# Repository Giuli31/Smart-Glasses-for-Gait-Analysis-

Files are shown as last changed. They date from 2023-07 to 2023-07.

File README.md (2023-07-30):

# Smart Glasses for Gait Analysis in Parkinson’s Disease 
## Table of contents
* [General info](#general-info)
* [Technologies](#technologies)
* [How To Use](#how-to-use)

## General info
Parkinson’s disease (PD) is one of the most common neurodegenerative disorders of the central nervous system, which predominantly affects patients’ motor functions, movement, and stability. In recent years, there has been an increase in the usage of wearable sensors for PD symptom monitoring aiming at anticipating the disease diagnosis and thus providing a most efficient quality of care. In this context, the developed device aims to provide objective information on the motor state, analysing the patient's gait and classifying it. In order to accomplish this task, the SGGA device is based on the Timed Up and Go (TUG) test. This is a simple test to measure a person’s level of mobility. It measures the time it takes for a person to get up from a chair, walk three meters, turn around, return to the chair and sit down again. Some sources suggest that a score of 10 seconds or less indicates normal mobility; times between 11 and 20 seconds are within normal limits for elderly with fragility and disabled patients; times longer than 20 seconds indicate that the person needs external assistance and the need for further examinations and interventions. A score greater than 30 seconds suggests that the person may be prone to falls. The TUG was developed from a more articulated test, the Get-up and Go. The SGGA device isn't a classifier of Parkinson’s disease, but it can be a useful tool for the study of symptoms and progression of this disease. 

## Technologies
Project is created with:
* EAGLE - for the design of the PCB
* PSoC Creator - for the program of the microcontroller 
* PyQt5 - for the development the graphical user interface

## How To Use
* [Physical Device](#physical-device)
* [Interface](#interface)
* [Acquisition](#acquisition)
* [Bugs](#bugs)

### Physical Device
The SGGA device is a wearable device composed by two main parts. The first is a small case equipped with accelerometer and wearable on the own glasses or given glasses. The second part is a bigger case that contains the PCB and its components. It's equipped with a belt that must be fastened around the patient’s waist. On the short side of the case, it's possible to check the state of the SGGA device thanks to the presence of two LEDs. The red LED shows that the device is powered, so it works. The green LED shows the connection established between the device and the application. In particular, the green flashing LED indicates that the device is ready to send data to the application, while, when the green LED becomes fixed, it indicates that the device is sending data registered by the accelerometer to the application. 

### Interface
The graphic user interface allows the user to visualize the results of the Timed Up and Go (TUG) test. On the right side of the screen, it is possible to see a graph that shows the acceleration trend over time. On the left side there are two tabs: "Acquisition" and "Excel files". 
The tab "Acquisition" contains buttons "Start Acquisition", "Stop Acquisition", "Save Data", "New Session" and "Search for device". Here it is also possible to visualize a timer and a steps counter. 
The tab "Excel files" shows past acquisitions that are saved on Excel files named with data and progression number of session. Clicking on one of these files, it is possible to visualize on the screen a number between 0 and 2 that indicates the class of the result (0 - Normal Gait, 1 - Require further examinations, 2 - Patient need assistance). This classification is made using a machine learning model, the Decision Trees, that is trained using a set of acquisitions based on TUG test permed by healthy subject trying also to reproduce the gait of impaired people. 

### Acquisition 
The first step of the acquisition is the preparation of the patient. He/She should wear the belt and place the case on the side so that the LED lights are visible. Red LED will light up when the device is connected to the power supply. After that, the patient must wear glasses equipped with the second smaller case. Let sit the patient in the chair and so he/she is ready for the test. 

Now, the user has to run the application using the Python file named "FinalGUI.py" and start the pairing of the device with the application. Once the GUI is open, the user must push the button "Search for device" in order to connect the device, if the connection is successful the green LED will start flashing. At this point, the device is ready for start the acquisition. 

When the patient is ready to perform the test, the user has to push the button "Start Acquisition" and the timer and the steps counter start at the same time. On the graph it's possible to visualize in real-time the acceleration trend of the patient's walk. 

Once the patient has completed the test, the user has to push the button "Stop acquisition". At this point a dynamic window will open and it will show the result of the test, classifying it into "Normal gait detected", "Anomalous gait detected. Further examinations suggested" or "Serious anomalies on gait detected. Subject may require assistances". On the same window, it is asked to the user if he wants to save the result of test, in positive case clicking on "Yes". 

Now it is possible to start a new acquisition pushing again the button "Start Acquisition". 

At the end of the test, it is possible to save the entire session of acquisitions pushing the button "Save Data". These data are saved in files contained in the tab "Excel files". 

In order to start a new session of acquisitions, the user has to push the button "New session" and repeat all the previous steps. 

### Bugs
During the pairing between device and application may happen that the device fails to access the serial port. In this case, a dynamic window will open showing the wrong serial port and the message "ERROR PORT CONNECTION: ". It is recommended to reset the application.

(This project is the result of teamwork)

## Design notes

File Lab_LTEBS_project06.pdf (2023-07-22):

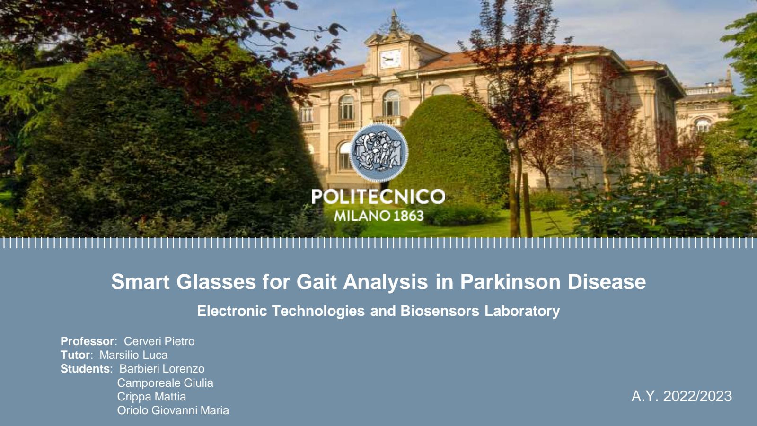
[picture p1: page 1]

# Titolo presentazione sottotitolo

## Milano, XX mese 20XX

## Smart Glasses for Gait Analysis in Parkinson Disease

Electronic Technologies and Biosensors Laboratory

A.Y. 2022/2023

Professor: Cerveri Pietro
Tutor: Marsilio Luca
Students: Barbieri Lorenzo Camporeale Giulia
Crippa Mattia
Oriolo Giovanni Maria

## Introduzione e contesto

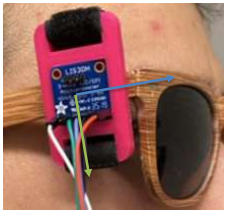
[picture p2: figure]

Electronic Technologies and Biosensors Laboratory

Obiettivo del device?

Come?

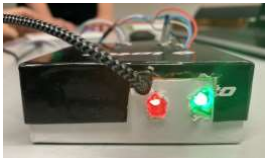
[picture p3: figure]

Contesto di utilizzo? Ausilio valutazione condizione del paziente, test di prima valutazione/conoscitivo. Può essere utilizzato sia in ambito clinico che domiciliare con ausilio persona esterna (anche non qualificata).

Classificare camminata del paziente

TUG test
Acquisizione parametri inerziali e temporali

Obiettivo:
Analisi preliminare della capacità di fornire informazioni oggettive sullo stato motorio di pazienti Parkinson da parte di occhiali smart

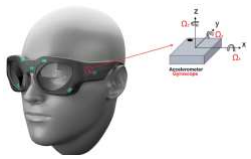
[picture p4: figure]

Protocollo sperimentale:
TUG test indossando occhiali e compilazione due questionari (target)

Conclusioni:
Occhiali smart si sono dimostrati potenzialmente utili a fornire informazioni quantitative riguardo lo stato dei pazienti Parkinson

## Stato dell'arte: revisione della letteratura

https://doi.org/10.1101/2022.10.22.22281214

## Hardware setup

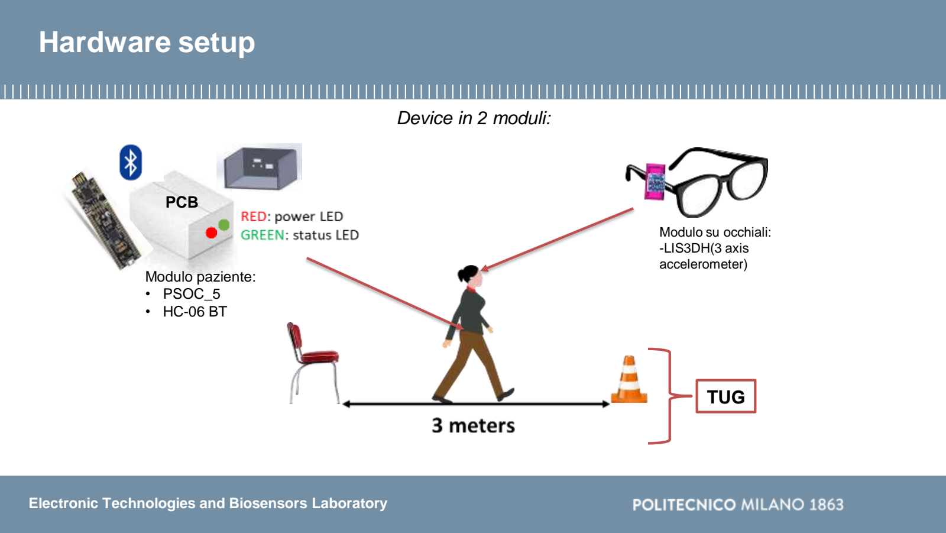
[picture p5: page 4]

PCB

Modulo paziente:
- PSOC_5
- HC-06 BT

TUG

Device in 2 moduli:

Modulo su occhiali:
-LIS3DH(3 axis
accelerometer)

## Software integration

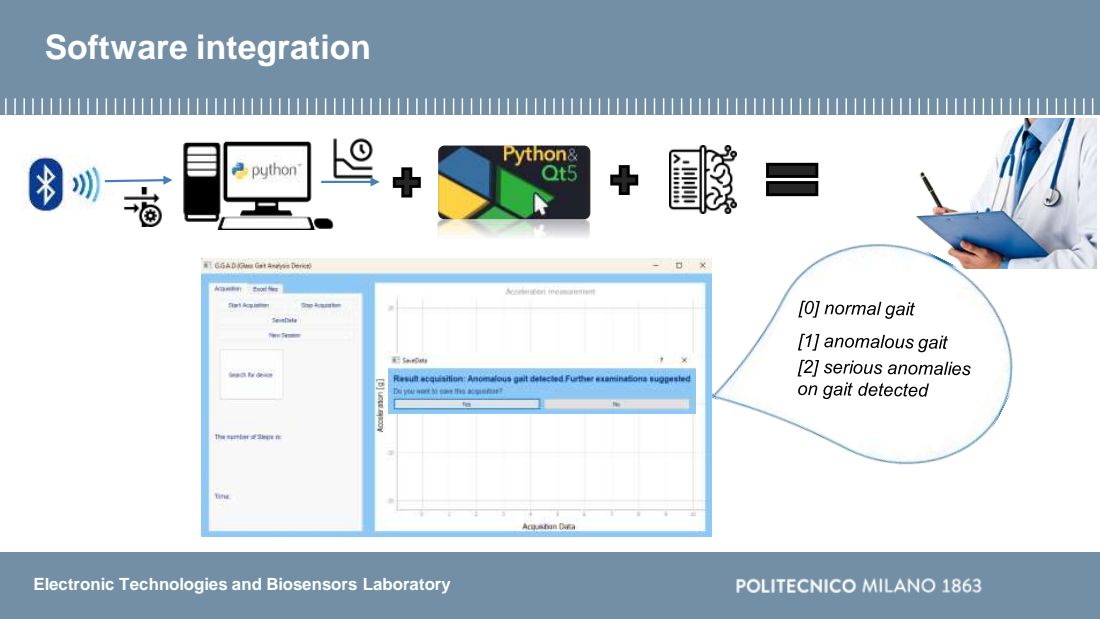
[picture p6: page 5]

4 soggetti sani, età 24 anni (20 –30 sessioni)

Cammino anomalo simulato (FOG, ridotta

mobilità)

## Experimental setup

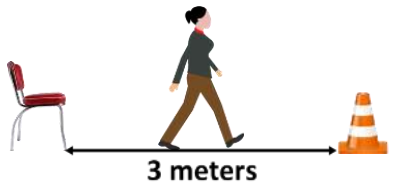
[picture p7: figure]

Posizionamento sensore

Soggetti coinvolti

Classificazione a 3 stati

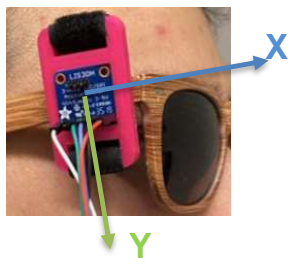
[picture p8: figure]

Ai soggetti è stato richiesto il tipo di

cammino simulato alla fine di ogni sessione.

Target inserito manualmente.

[0] = normal [1] = anomalous [2] = assistance

Protocollo sperimentale

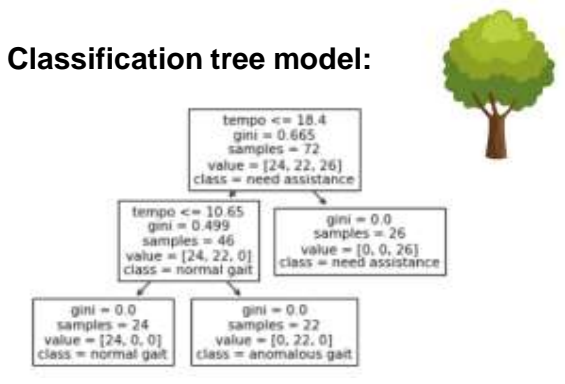
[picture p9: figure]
Classification tree model:
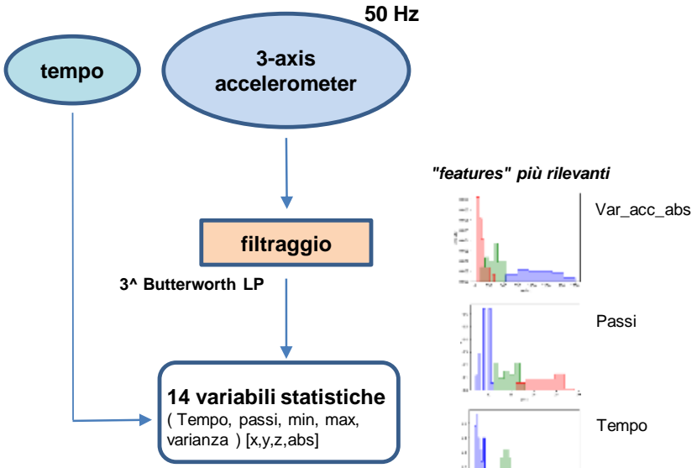
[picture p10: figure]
3-axis accelerometer; filtraggio; tempo; 14 variabili statistiche; ( Tempo, passi, min, max, varianza ) [x,y,z,abs]; Var_acc_abs; Tempo; Passi; 3^ Butterworth LP; "features" più rilevanti

Tempo (t) come discriminante assoluta:

normal gait | t < 10.65 s
anomalous gait | 10.65 s < t < 18.4 s
need assistance | t > 18.4 s

## Data processing e model training

- Connessione tra microcontrollore e PC stabile e veloce tramite bluetooth
- Definito un valido algoritmo per il conteggio dei passi
- Implementazione di una semplice interfaccia grafica con l'utente (GUI)
- Classificazione three-state del paziente tramite modello ML
- Progetto e realizzazione PCB
- Modello CAD 3D per il case

## Conclusioni

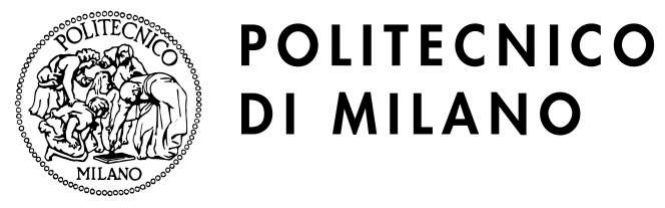
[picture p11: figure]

# Thank you for your attention!

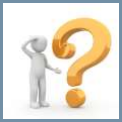
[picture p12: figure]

# Any question?

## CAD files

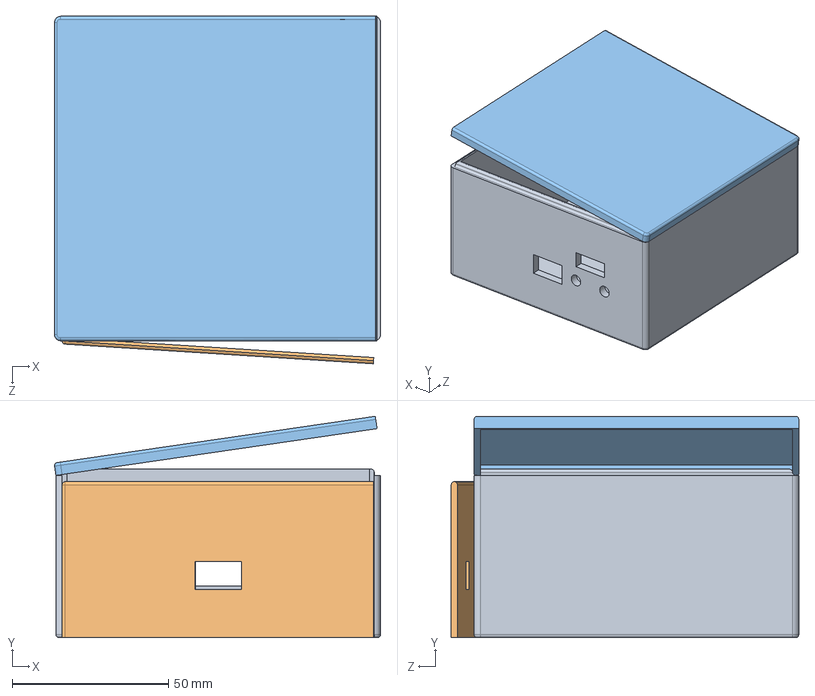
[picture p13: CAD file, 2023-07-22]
Case_3D/Assieme_final.SLDASM
104.4 x 70.9 x 111.4 mm
ParteA_final
ParteC_final
ParteB_final

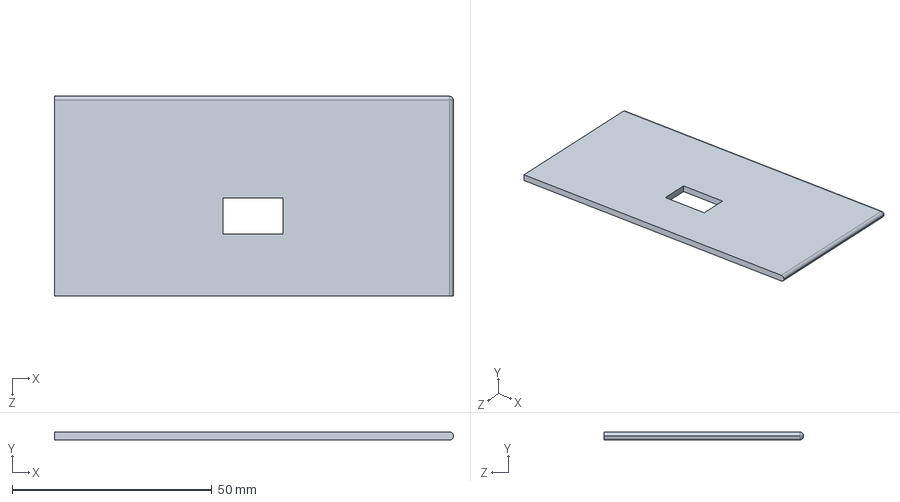
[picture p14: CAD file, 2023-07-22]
Case_3D/ParteC_final.SLDPRT
100.0 x 2.00 x 50.0 mm

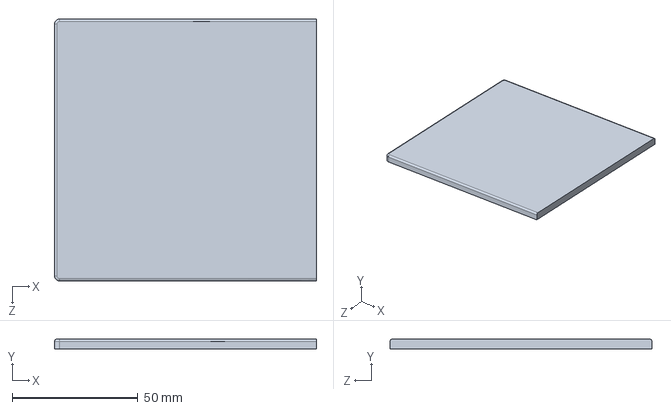
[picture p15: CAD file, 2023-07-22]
Case_3D/ParteB_final.SLDPRT
104.0 x 4.00 x 104.0 mm

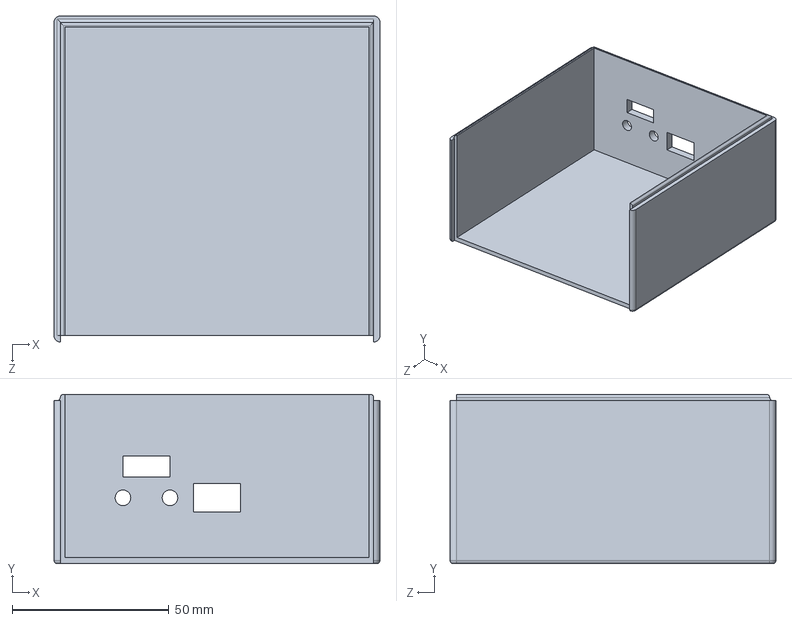
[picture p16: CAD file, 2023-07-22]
Case_3D/ParteA_final.SLDPRT
104.0 x 54.0 x 104.0 mm

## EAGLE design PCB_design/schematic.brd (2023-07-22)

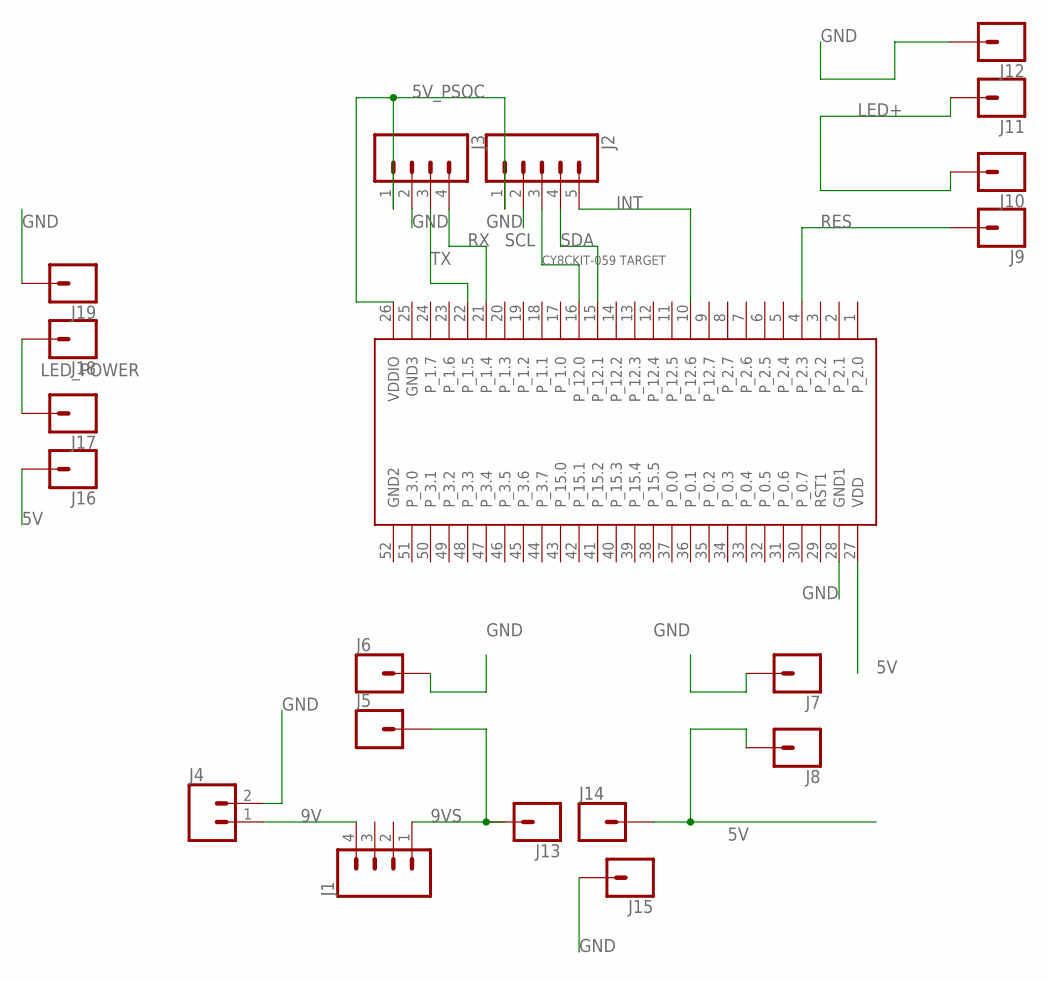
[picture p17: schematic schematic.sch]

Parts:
J1, J3: CONN_041X04_NO_SILK; 1X04_NO_SILK
J2: CONN_05NO_SILK; 1X05_NO_SILK
J4: CONN_021X02_NO_SILK; 1X02_NO_SILK
J5, J6, J7, J8, J9, J10, J11, J12, J13, J14, J15, J16, J17, J18, J19: CONN_01PTH_NO_SILK_YES_STOP; 1X01_NO_SILK
U$2: CY8CKIT-059_TARGET_3

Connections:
5V: J8.1, J14.1, J16.1, U$2.27 (VDD)
5V_PSOC: J2.1, J3.1, U$2.26 (VDDIO)
9V: J1.4, J4.1
9VS: J1.1, J5.1, J13.1
GND: J2.2, J3.2, J4.2, J6.1, J7.1, J12.1, J15.1, J19.1, U$2.28 (GND1)
GND2: U$2.52 (GND2)
GND3: U$2.25 (GND3)
INT: J2.5, U$2.10 (P_12.6)
LED+: J10.1, J11.1
LED_POWER: J17.1, J18.1
RES: J9.1, U$2.4 (P_2.3)
RX: J3.4, U$2.21 (P_1.4)
SCL: J2.3, U$2.16 (P_12.0)
SDA: J2.4, U$2.15 (P_12.1)
TX: J3.3, U$2.22 (P_1.5)

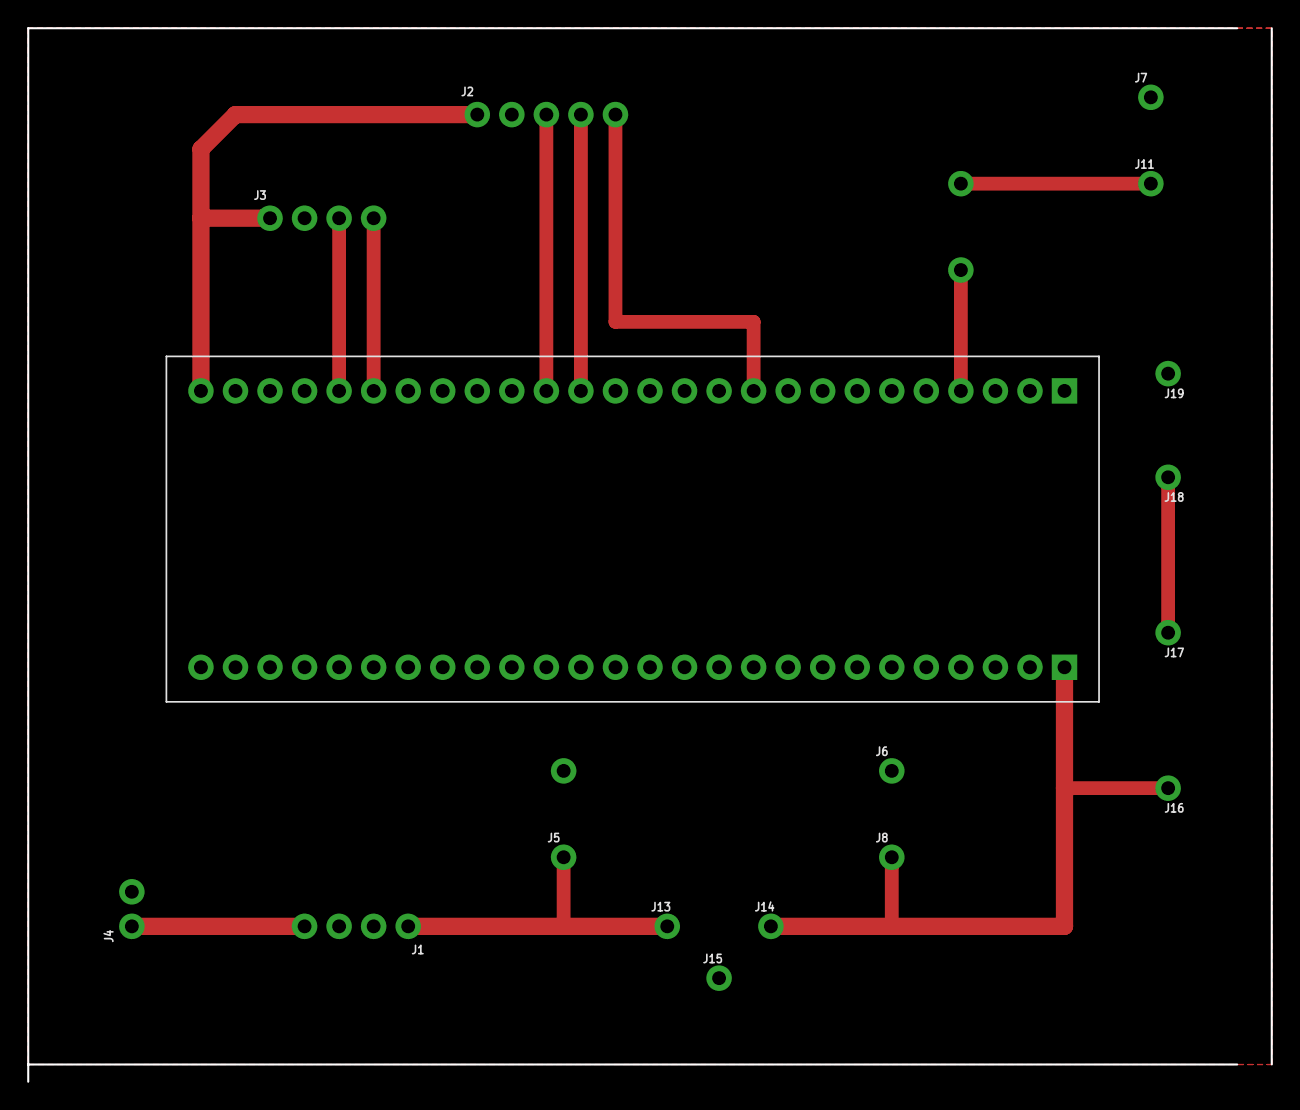
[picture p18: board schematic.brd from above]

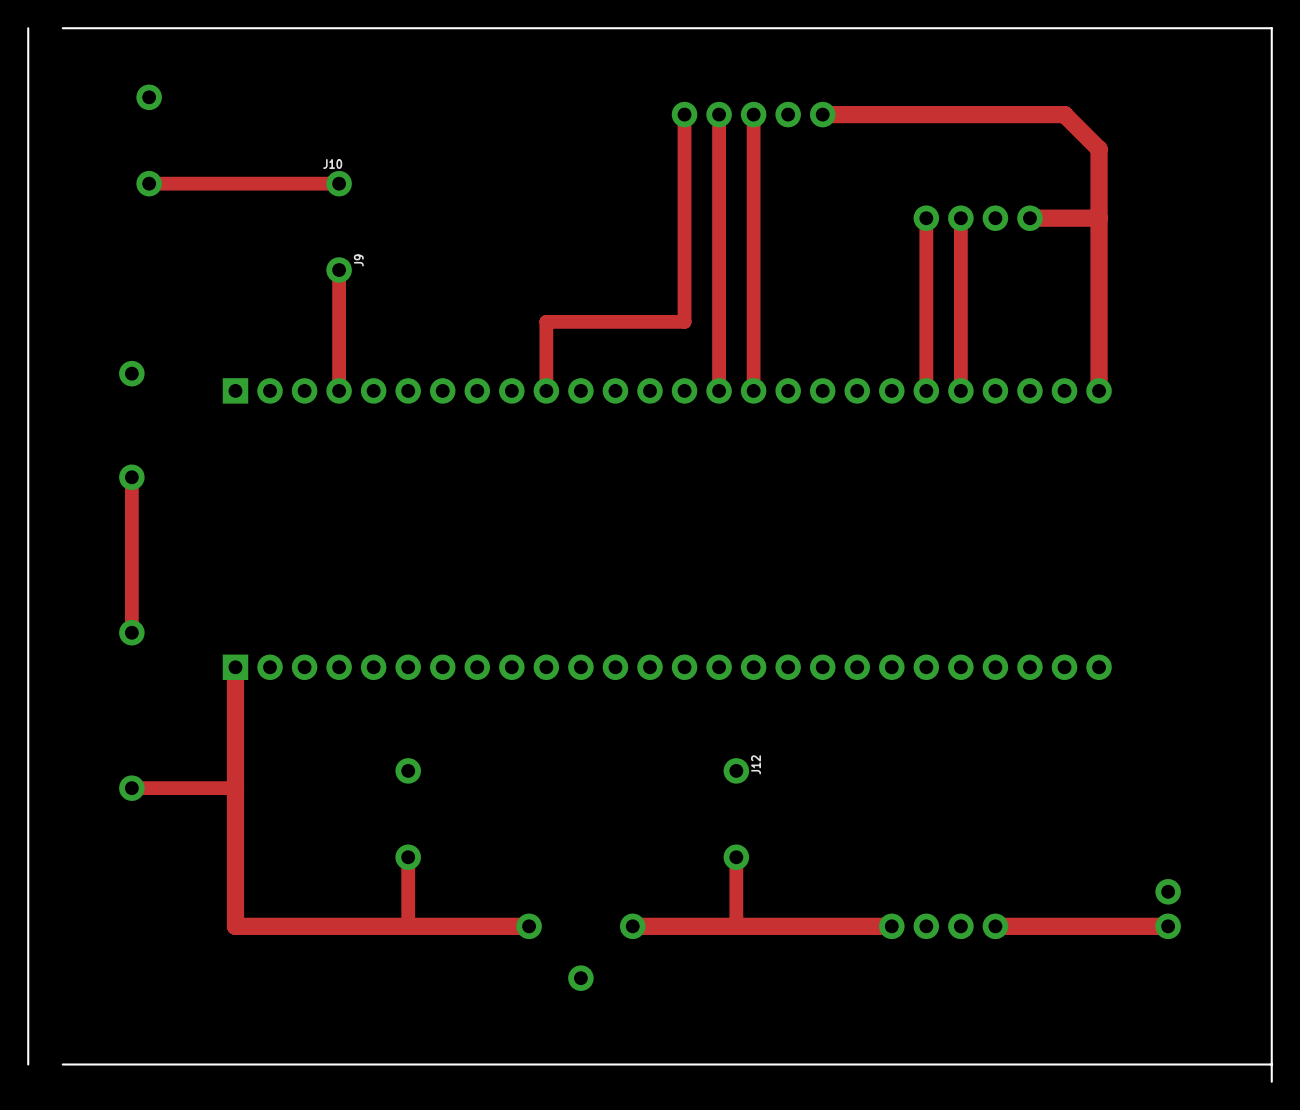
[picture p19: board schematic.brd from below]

Board: 2 copper layers, 91.4 x 77.5 mm, 20 parts (3 on the bottom side), 13 nets.

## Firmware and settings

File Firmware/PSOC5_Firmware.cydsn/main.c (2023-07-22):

/* ========================================
 *
 * Copyright YOUR COMPANY, THE YEAR
 * All Rights Reserved
 * UNPUBLISHED, LICENSED SOFTWARE.
 *
 * CONFIDENTIAL AND PROPRIETARY INFORMATION
 * WHICH IS THE PROPERTY OF your company.
 *
 * ========================================
*/
#include <stdio.h>
#include "project.h"
#include "Interrupt_Routines.h"
#include "Initialization.h"
#include "../src_shared/I2C_Interface.h"

int main(void)
{
    /*Enable communications:I2C [PSOC <--> LIS3DH] | UART [PSOC <--> HC-06]. */
    I2C_Peripheral_Start();
    UART_1_Start();
    /*Enable interrupts. */
    CyGlobalIntEnable; /* Enable global interrupts. */
    Pin_int_isr_StartEx(Custom_ISR_PIN);
    RX_isr_StartEx(Custom_ISR_RX);
    /*Initialization of the LEDs and LIS3DH accelerometer */
    INIT_LEDs();
    CHECK_LIS3DH();
    INIT_LIS3DH();
    CyDelay(5); 
    
    for(;;)
    {

    }
}

/* [] END OF FILE */
       

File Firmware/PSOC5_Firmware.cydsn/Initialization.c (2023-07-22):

/* ========================================
 *
 * Copyright YOUR COMPANY, THE YEAR
 * All Rights Reserved
 * UNPUBLISHED, LICENSED SOFTWARE.
 *
 * CONFIDENTIAL AND PROPRIETARY INFORMATION
 * WHICH IS THE PROPERTY OF your company.
 *
 * ========================================
*/
#include "cytypes.h"
#include "Initialization.h"
#include "Pin_LED.h"
#include "LED_LIS3DH.h"
#include "UART_1.h"
#include "I2C_Master.h"
#include "../src_shared/I2C_Interface.h"
#include "../src_shared/LIS3DH.h"
#define LOW 0
#define HIGH 1
ErrorCode error;

/*  LED initialization function */
void INIT_LEDs() {
    Pin_LED_Write(LOW);
    LED_LIS3DH_Write(LOW);
}
/*  LIS3DH check connection  */
void CHECK_LIS3DH() {
    int32_t rval = I2C_Master_MasterSendStart(LIS3DH_DEVICE_ADDRESS, I2C_Master_WRITE_XFER_MODE);
    if( rval == I2C_Master_MSTR_NO_ERROR ) {
        //UART_1_PutString("LIS3DH found @ address 0x18\r\n");
        LED_LIS3DH_Write(LOW);
    }
    else {
        LED_LIS3DH_Write(HIGH);
    }
    I2C_Master_MasterSendStop();
}
/*  LIS3DH Initialization  */
void INIT_LIS3DH() {
    uint8_t axis_enable_data_rate = 0b01000111;
    error = I2C_Peripheral_WriteRegister(LIS3DH_DEVICE_ADDRESS,
                                         LIS3DH_CTRL_REG1,
                                         axis_enable_data_rate);
    // set FS +/- 2g
    uint8_t ctrl_reg4 = 0b00000000;   
    error = I2C_Peripheral_WriteRegister(LIS3DH_DEVICE_ADDRESS,
                                         LIS3DH_CTRL_REG4,
                                         ctrl_reg4);

    // setting FIFO register
    uint8 fifo_enable, fifo_FIFO, fifo_BYPASS, overrun_enable;
    // enable fifo
    error = I2C_Peripheral_ReadRegister(LIS3DH_DEVICE_ADDRESS,
                                        LIS3DH__CTRL_REG5,
                                        &fifo_enable);
    fifo_enable = fifo_enable | 0b11000000;
    error = I2C_Peripheral_WriteRegister(LIS3DH_DEVICE_ADDRESS,
                                         LIS3DH__CTRL_REG5,
                                         fifo_enable);
    // put fifo in FIFO mode
    fifo_FIFO = 0b01000000;
    error = I2C_Peripheral_WriteRegister(LIS3DH_DEVICE_ADDRESS,
                                         LIS3DH__FIFO_CTRL_REG,
                                         fifo_FIFO);
    // overrun interrupt enable on INT_1 pin
    error = I2C_Peripheral_ReadRegister(LIS3DH_DEVICE_ADDRESS,
                                        LIS3DH_FIFO_CTRL_REG3,
                                        &overrun_enable);
    overrun_enable = overrun_enable | 0b00000010;
    error = I2C_Peripheral_WriteRegister(LIS3DH_DEVICE_ADDRESS,
                                         LIS3DH_FIFO_CTRL_REG3,
                                         overrun_enable);
    // reset FIFO registers content
    fifo_BYPASS = 0;
    error = I2C_Peripheral_WriteRegister(LIS3DH_DEVICE_ADDRESS,
                                         LIS3DH__FIFO_CTRL_REG,
                                         fifo_BYPASS);;
    error = I2C_Peripheral_WriteRegister(LIS3DH_DEVICE_ADDRESS,
                                         LIS3DH__FIFO_CTRL_REG,
                                         fifo_FIFO); 
}
/* [] END OF FILE */

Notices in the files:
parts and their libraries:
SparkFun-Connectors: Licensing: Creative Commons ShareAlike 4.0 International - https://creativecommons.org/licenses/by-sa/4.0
